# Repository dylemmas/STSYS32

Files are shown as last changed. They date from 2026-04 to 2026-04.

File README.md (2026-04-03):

# STASYS ESP32

Market-ready ESP32 firmware for shooter athlete muzzle trace and shot detection.

## Firmware Version
v1.0.0

## Hardware
- ESP32 DEVKIT V1
- MPU6050 (IMU: 6-axis accel+gyro, I2C)
- TP4056 (LiPo charge module)
- Piezoelectric vibration sensor
- LiPo 3.7V battery
- Picatinny rail mount

## Features
- Interrupt-driven MPU6050 sensor reading (1kHz)
- Dual-threshold shot detection (piezo + accelerometer)
- Configurable sample rate (50/100/200 Hz)
- Configurable shot detection thresholds
- Session management (start/stop, shot count, duration)
- Bluetooth Classic SPP binary protocol
- LED + haptic feedback on shot detection
- Battery monitoring with charging status
- NVS-based persistent configuration
- Watchdog timers for reliability
- I2C error recovery

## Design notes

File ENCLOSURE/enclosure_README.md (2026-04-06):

# STASYS Enclosure — 3D Printable Design

Parametric OpenSCAD models for the STASYS training device enclosure.

## Files

| File | Description |
|---|---|
| `STASYS_enclosure.scad` | Full parametric model (all-in-one, assembly view) |
| `enclosure_base.scad` | Base half only — export as STL for printing |
| `enclosure_lid.scad` | Lid half only — export as STL for printing |
| `enclosure_BOM.md` | Bill of materials + assembly guide |

## Quick Start

1. Install [OpenSCAD](https://openscad.org/) (free, Windows/Mac/Linux)
2. Open `enclosure_base.scad`
3. Press **F5** for preview or **F6** for full render
4. Press **F7** to export as STL
5. Repeat for `enclosure_lid.scad`
6. Slice in your slicer (PrusaSlicer, Cura, Lychee, etc.)
7. Print in PA12 SLS or high-strength SLA resin

## Design Overview

```
TOP VIEW (cross-section at Z=max)

        ┌─────────────────────────────────────┐
        │  ╔═══════════════════════════════╗  │
        │  ║                               ║  │
        │  ║     INTERNAL CAVITY           ║  │
        │  ║   ┌─────────────────────┐    ║  │
        │  ║   │   ESP32 DEVKIT V1   │    ║  │
        │  ║   │   + MPU6050 + wires │    ║  │
        │  ║   │   + LiPo battery   │    ║  │
        │  ║   └─────────────────────┘    ║  │
        │  ║                               ║  │
        │  ╚═══════════════════════════════╝  │
        └─────────────────────────────────────┘
              ↑↑       ↑↑  ← GASKET CHANNEL (perimeter)
             (slots straddle Picatinny rail slots)

FRONT VIEW

     ┌─────────────────────────┐
     │  LED PIPE  │  VENT PORT│
     ├─────────────────────────┤
     │                         │
     │    INTERNAL CAVITY      │
     │                         │
     ├─────────────────────────┤
     │         USB-C           │
     └─────────────────────────┘
              ↓
        PICATINNY RAIL
        (slots engage below)

BOTTOM VIEW

        ════════════════════     ← Picatinny rail slot
        │▓▓▓▓▓│     │▓▓▓▓▓│        ← Recoil lugs (2x)
        │     │     │     │
        │     └─────┘     │        ← Cross-bolt goes here
        │                 │
        └─────────────────┘
        ┌─────────────────┐
        │ ● ● ● ●        │        ← MPU6050 recess
        │    PIEZO ●     │        ← Piezo contact pad
        └─────────────────┘
```

## Key Dimensions

| Parameter | Value |
|---|---|
| Outer (W×D×H) | 65×50×34 mm |
| Internal cavity | 60×45×22 mm |
| Wall thickness | 2.5 mm |
| Base height | 8 mm |
| Lid height | 4 mm |
| Picatinny body | 24 mm (2 slots) |
| Recoil lug | 3 mm protrusion |
| Weight (printed PA12) | ~30g (base + lid) |
| Total with hardware | ~36g |
| Total on weapon | ~86g (with device) |

## Picatinny Rail Installation

1. Slide recoil lugs into Picatinny slot from the front
2. Slide device along rail until lugs sit in slot notch
3. Thread M3×16mm cross-bolt through base, into slot notch
4. Tighten to 0.5 N·m (hand tight + quarter turn)
5. Apply blue threadlocker to cross-bolt

## Parameter Customization

All key dimensions are defined at the top of each `.scad` file. Adjust these before rendering:

```scad
// Main dimensions
INNER_WIDTH = 60;      // Change if your PCB is wider
INNER_DEPTH = 45;      // Change if your PCB is deeper
WALL = 2.5;             // 2.0mm for SLA, 2.5mm for PA12

// Picatinny engagement
PICA_SLOTS = 2;         // 1 slot = less stable, 3 slots = more stable
RECOIL_LUG_H = 3.0;     // Increase if slot is deeper

// Component clearances
MPU6050_OFF_X = 6;      // Reposition MPU6050 pocket
PIEZO_PAD_D = 10;        // Larger/smaller piezo contact
```

## Recommended Print Settings

### PA12 SLS (recommended for base)
- Layer height: 60 µm
- Wall thickness: 2.5mm (3 perimeters)
- No supports needed (flat on build plate)
- Post-process: bead blast or tumble for surface smoothness

### High-Strength SLA
- Layer height: 50 µm
- Wall thickness: 2.0mm
- Material: Formlabs Durable, Siraya Tech Fast ABS, or equivalent
- Post-cure: 30 min at 60°C

## Post-Processing

1. **Heat-set inserts**: Soldering iron 250°C, press M3 brass inserts flush into base bosses
2. **Sand + prime**: 400-grit for support marks, filler primer for SLA
3. **Threadlocker**: Blue Loctite 243 on cross-bolt threads
4. **Silicone gasket**: Cut from 1mm sheet (see enclosure_BOM.md)

## Notes

- The base and lid are designed to be printed flat (no supports needed)
- PA12 SLS is recommended for the base due to fatigue resistance from recoil
- SLA resin is acceptable for the lid (non-structural)
- The Picatinny body extends 2.5mm beyond the main body on each side
- The recoil lugs are designed for MIL-STD-1913 Picatinny rails
- For Weaver rails (0.180" slots), file the lugs slightly narrower

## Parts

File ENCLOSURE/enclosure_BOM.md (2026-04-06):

# STASYS Enclosure — Bill of Materials

## 3D Printed Parts

| Qty | Part | File | Material | Print Orientation |
|-----|---|---|---|---|
| 1 | Base (bottom half + Picatinny rail) | `enclosure_base.scad` | PA12 SLS (recommended) | Flat on build plate |
| 1 | Lid (top half) | `enclosure_lid.scad` | PA12 SLS (recommended) | Flat on build plate |
| 1 | Silicone gasket (optional) | Cut from 1mm silicone sheet | Silicone rubber | N/A |

**Alternative materials**: High-strength SLA resin (Formlabs Durable, Siraya Tech Fast ABS-like). Avoid standard clear/white SLA — brittle under recoil.

## Hardware (Purchase)

### Fasteners

| Qty | Description | Spec | Notes |
|-----|---|---|---|
| 4 | M3×0.5×6mm countersunk head screw | ISO 7380 | Lid-to-base assembly |
| 1 | M3×0.5×16mm socket head cap screw | ISO 4762 | Picatinny cross-bolt |
| 4 | M3 brass heat-set threaded insert | OD 4.2mm, ID M3, length 5mm | Base screw bosses |
| 4 | M3 flat washer | OD 6mm, ID 3.2mm | Under cross-bolt / lid screws |
| 1 | Threadlocker (blue Loctite 243) | Medium strength | On cross-bolt threads |

### Threaded Insert Reference
Install heat-set inserts into base after printing:
- **Method**: Preheat soldering iron to 250°C, press insert flush
- **PA12**: Pre-heat insert area with hot air gun first
- **SLA resin**: Can insert directly, no pre-heat needed

### Vent Membrane (Optional — for IP54)

| Qty | Description | Spec | Source |
|-----|---|---|---|
| 1 | ePTFE breathable membrane | 6mm disc, 0.2mm thick | e.g., eWON Vent (Digikey: 1834-1015-ND) |
| 1 | Vent housing ring (3D printed) | Fits VENT_PORT_D recess | Print with lid |

### Gasket (Optional — for IP54)

Cut from 1mm silicone sheet (craft rubber or silicone gasket material):
- Trace the outer perimeter of the base top face
- Cut out the inner rectangle (gasket channel)
- Punch holes at 4 screw positions
- Punch hole at vent port center

## Assembly Guide

### Tools Required
- Phillips #0 screwdriver (for M3 countersunk screws)
- 2.5mm hex key / 2.5mm hex driver (for cross-bolt)
- Soldering iron with 4mm flat tip (for heat-set inserts)
- Calipers (to verify dimensions)
- Multimeter (for electrical testing)

### Assembly Steps

#### Step 1: Post-Processing (SLA parts)
1. Remove supports carefully
2. Wash in IPA (or water for water-washable resin)
3. Post-cure per resin manufacturer's instructions (30 min at 60°C for Formlabs)
4. Sand any support marks with 400-grit sandpaper
5. Fill and prime if desired for surface finish

#### Step 2: Install Heat-Set Inserts (Base)
1. Heat soldering iron to 250°C
2. Using tweezers, place insert into base screw boss hole
3. Press insert flush with flat face of iron
4. Insert should melt into plastic, sit 0.2mm below surface
5. Let cool 30 seconds before handling
6. Repeat for all 4 bosses

#### Step 3: Test Fit
1. Place ESP32 DEVKIT V1 into base cavity — verify clearances
2. Test lid fits on base — verify gasket channel alignment
3. Test M3 screws thread into inserts smoothly

#### Step 4: Wire Routing
1. Route USB-C cable from ESP32 to USB cutout on side
2. Route MPU6050 I2C wires to front area
3. Route piezo wire to piezo contact pad location
4. Use small zip ties or adhesive foam to secure wires

#### Step 5: Install Vent Membrane (Optional)
1. Apply thin layer of silicone adhesive around vent port recess
2. Press ePTFE membrane disc into recess
3. Let cure 24 hours before assembly

#### Step 6: Install Silicone Gasket (Optional)
1. Cut gasket from 1mm silicone sheet
2. Place gasket into base gasket channel
3. Verify gasket is seated fully in channel

#### Step 7: Final Assembly
1. Insert ESP32 DEVKIT V1 + wiring into base
2. Place lid on base — align carefully
3. Install 4× M3×6mm countersunk screws — snug, do not over-torque
4. Torque: 0.3–0.5 N·m (hand tight plus 1/4 turn with hex key)

#### Step 8: Picatinny Rail Installation
1. Slide recoil lug into Picatinny slot from the front
2. Slide device along rail until lug sits in slot notch
3. Thread M3×16mm cross-bolt through base, into slot notch
4. Tighten cross-bolt with hex key — 0.5 N·m (hand tight)
5. Apply blue threadlocker to bolt threads before final tightening

### Disassembly for Programming
1. Loosen cross-bolt, slide device off rail
2. Remove 4 lid screws
3. Lift lid off
4. Access USB-C port for programming
5. Reassemble in reverse order

## Dimension Summary

```
┌─────────────────────────────────────────────┐
│ ENCLOSURE OUTER (W×D×H): 65 × 50 × 34 mm   │
│ INTERNAL CAVITY (W×D×H): 60 × 45 × 22 mm   │
│ BASE HEIGHT: 8 mm                           │
│ LID HEIGHT: 4 mm                            │
│ WALL THICKNESS: 2.5 mm                      │
│ PICA BODY WIDTH: 24 mm (2-slot)            │
│ RECOIL LUG HEIGHT: 3 mm                     │
│ CROSS-BOLT: M3×16mm                        │
│ LID SCREWS: M3×6mm countersunk (4x)         │
│ BATTERY RECESS: 54×38×2 mm                 │
│ MPU6050 POCKET: 23×18×2 mm                 │
│ PIEZO PAD: Ø10mm × 2mm protrusion          │
│ LED PIPE: Ø2.5mm bore                      │
│ VENT PORT: Ø6mm recess                      │
│ USB CUTOUT: 10×8mm on side face             │
└─────────────────────────────────────────────┘
```

## Estimated Weight

| Component | Weight |
|---|---|
| Base (PA12 printed, ~25g) | ~20g |
| Lid (PA12 printed, ~12g) | ~10g |
| Gasket (silicone, 1mm) | ~2g |
| M3×6mm screws (4x) | ~2g |
| M3×16mm cross-bolt | ~1g |
| Heat-set inserts (4x) | ~1g |
| **Total** | **~36g** |
| + Device (ESP32 + components + battery) | ~50g |
| **Grand total on weapon** | **~86g** |

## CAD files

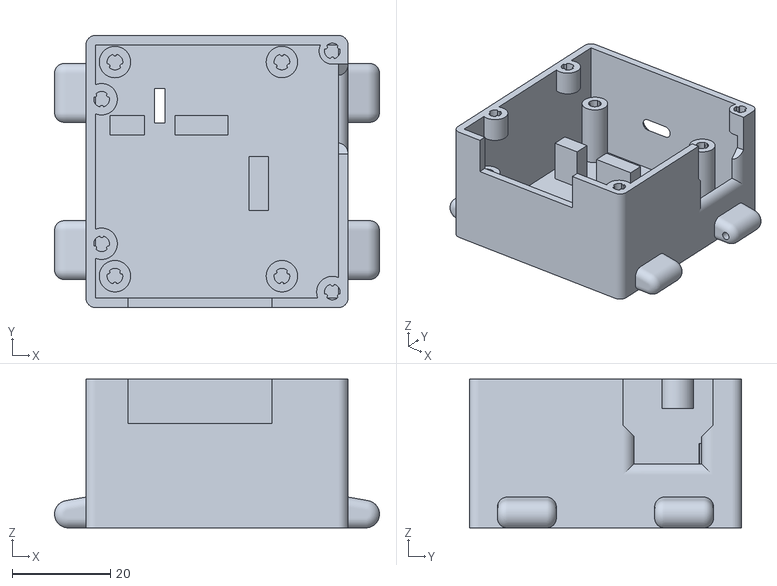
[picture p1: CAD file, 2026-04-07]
ENCLOSURE/MainCase watch esp 32.stl
66.2 x 55.5 x 30.3

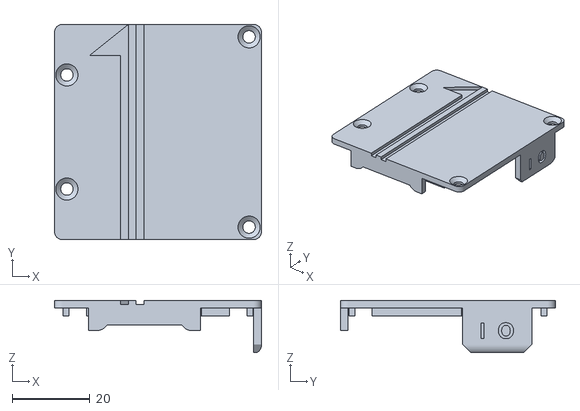
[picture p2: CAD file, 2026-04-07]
ENCLOSURE/Lid watch esp 32.stl
53.4 x 55.5 x 13.5

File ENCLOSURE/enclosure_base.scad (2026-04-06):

// STASYS Enclosure — BASE (Bottom Half)
// OpenSCAD model for SLA/SLS 3D printing
// Print: flat on build plate, no supports
//
// Hardware BOM: see enclosure_BOM.md
//
// Material: PA12 SLS recommended (tough, fatigue-resistant)
// SLA: use high-strength resin (Formlabs Durable, Siraya Tech Fast ABS)
//

// ===============================
// PARAMETERS
// ===============================
/* [Main Dimensions] */
INNER_WIDTH = 60;      // Internal X — must fit ESP32 DEVKIT V1 (~55mm)
INNER_DEPTH = 45;      // Internal Y — must fit DEVKIT V1 (~27mm) + wiring
INNER_HEIGHT = 22;     // Internal Z height — DEVKIT V1 (~20mm) + components
WALL = 2.5;           // Wall thickness: 2.0mm SLA, 2.5mm PA12/SLS
BASE_HEIGHT = 8;       // Height of Picatinny mount body (below cavity)
LID_HEIGHT = 4;        // Lid cap height

/* [Picatinny Rail Interface] */
PICA_SPACING = 10.01; // MIL-STD-1913 slot spacing
PICA_SLOTS = 2;        // Number of rail slots base straddles
CROSSBOLT_D = 3.0;     // Cross-bolt (M3) diameter
RECOIL_LUG_H = 3.0;    // Lug protrusion into Picatinny slot notch

/* [Components] */
MPU6050_OFFSET_X = 6;  // MPU6050 position from base inner corner
MPU6050_OFFSET_Y = 6;
MPU6050_W = 21;
MPU6050_D = 16;
BATTERY_L = 50;
BATTERY_W = 34;

/* [Hardware] */
SCREW_D = 3.0;         // M3 screw diameter
SCREW_HEAD_D = 6.0;    // M3 countersunk head diameter
SCREW_CSINK = 1.5;     // Countersink depth
INSERT_D = 4.4;         // M3 heat-set insert OD

/* [Gasket] */
GASKET_D = 1.0;        // Gasket channel depth (into base top face)
GASKET_W = 2.0;        // Gasket channel width

/* [Features] */
USB_W = 10;            // USB-C cutout width
LED_PIPE_D = 2.5;      // LED light pipe bore diameter
VENT_D = 6.0;          // Vent membrane port diameter
PIEZO_PAD_D = 10;      // Piezo contact pad diameter
PIEZO_PAD_H = 2;       // Piezo pad protrusion

$fn = 64;

// ===============================
// COMPUTED
// ===============================
OUTER_W = INNER_WIDTH + 2 * WALL;
OUTER_D = INNER_DEPTH + 2 * WALL;
OUTER_H = BASE_HEIGHT + INNER_HEIGHT + LID_HEIGHT;
PICA_BODY_W = PICA_SLOTS * PICA_SPACING + 4;

BOSS_INSET = 5;
boss_pos = [
    [BOSS_INSET, BOSS_INSET],
    [BOSS_INSET, OUTER_D - BOSS_INSET],
    [OUTER_W - BOSS_INSET, BOSS_INSET],
    [OUTER_W - BOSS_INSET, OUTER_D - BOSS_INSET]
];

// ===============================
// GASKET CHANNEL 2D — using offset for clean geometry
// ===============================
// Outer boundary minus inner boundary = channel ring
// offset(-GASKET_D) shrinks inner rect, creating channel
module gasket_channel_2d() {
    difference() {
        square([OUTER_W, OUTER_H]);
        offset(delta = -GASKET_D)
            square([OUTER_W, OUTER_H]);
    }
    // Also cut a ring around the inner island
    // (inner island: INNER_W × INNER_D, shrunk by GASKET_W)
    intersection() {
        difference() {
            offset(delta = -GASKET_D)
                square([OUTER_W, OUTER_H]);
            offset(delta = -(GASKET_D + GASKET_W))
                square([OUTER_W, OUTER_H]);
        }
        square([OUTER_W, OUTER_H]);
    }
}

// ===============================
// BASE — 2D profile then extrude
// ===============================
module base_profile_2d() {
    difference() {
        // Picatinny body extends beyond main body on X sides
        translate([(OUTER_W - PICA_BODY_W)/2, 0])
            square([PICA_BODY_W, OUTER_H]);

        // Main outer footprint (for union with Picatinny extension)
        union() {
            square([OUTER_W, OUTER_H]);
        }

        // Gasket channel on top face
        translate([0, BASE_HEIGHT + INNER_HEIGHT])
            gasket_channel_2d();

        // Screw counterbores (at top of base = lid mating face)
        translate([0, BASE_HEIGHT + INNER_HEIGHT])
            for (p = boss_pos)
                translate(p)
                    circle(d = SCREW_HEAD_D + 0.3);

        // Threaded insert holes (partially through top of base)
        translate([0, BASE_HEIGHT + INNER_HEIGHT - 2])
            for (p = boss_pos)
                translate(p)
                    circle(d = INSERT_D + 0.2);

        // LED pipe bore (through top)
        translate([OUTER_W - 10, OUTER_H + 1])
            circle(d = LED_PIPE_D + 0.5);

        // Vent port (center, for reference)
        translate([OUTER_W/2, OUTER_H/2])
            circle(d = VENT_D);
    }
}

// ===============================
// BASE 3D ASSEMBLY
// ===============================
// Outer shell
translate([0, 0, 0])
    linear_extrude(height = BASE_HEIGHT + INNER_HEIGHT)
        base_profile_2d();

// LED light pipe sleeve (protrudes above top face)
translate([OUTER_W - 10, OUTER_D/2, 0])
    cylinder(d = LED_PIPE_D - 0.5, h = BASE_HEIGHT + INNER_HEIGHT + 3);

// Cross-bolt channel (through Picatinny body, perpendicular to rail axis Y)
translate([(OUTER_W - PICA_BODY_W)/2 + 2, OUTER_D/2, 0])
    rotate([90, 0, 0])
        translate([0, 0, -PICA_BODY_W/2 - 2])
            cylinder(d = CROSSBOLT_D, h = PICA_BODY_W + 4);

// Screw through-holes (full depth)
for (p = boss_pos)
    translate([p[0], p[1], 0])
        cylinder(d = SCREW_D, h = BASE_HEIGHT + INNER_HEIGHT + LID_HEIGHT + 2);

// Counterbores
for (p = boss_pos)
    translate([p[0], p[1], BASE_HEIGHT + INNER_HEIGHT - SCREW_CSINK])
        cylinder(d = SCREW_HEAD_D + 0.3, h = SCREW_CSINK + 1);

// Threaded insert holes
for (p = boss_pos)
    translate([p[0], p[1], BASE_HEIGHT + INNER_HEIGHT])
        cylinder(d = INSERT_D, h = LID_HEIGHT + 2);

// USB cutout (Y=0 face)
translate([OUTER_W/2 - USB_W/2, -1, BASE_HEIGHT + INNER_HEIGHT/2 - 4])
    cube([USB_W, WALL + 2, 8]);

// LED bore (horizontal, through side)
translate([OUTER_W - 10, OUTER_D/2 + 2, BASE_HEIGHT + INNER_HEIGHT/2])
    rotate([0, 90, 0])
        cylinder(d = LED_PIPE_D + 0.5, h = WALL + 3);

// Recoil lugs (protrude from Picatinny body bottom)
translate([OUTER_W/2, 0, 0]) {
    half_span = (PICA_SLOTS * PICA_SPACING) / 2 - 1;
    for (x = [-half_span, half_span]) {
        translate([x, -0.1])
            hull() {
                circle(d = 6);
                translate([0, -RECOIL_LUG_H])
                    circle(d = 4);
            }
    }
}

// Interior cavity (hollow out)
translate([WALL, WALL, BASE_HEIGHT])
    cube([OUTER_W - 2*WALL, OUTER_D - 2*WALL, INNER_HEIGHT + 1]);

// PCB standoffs (inside base, on bottom)
translate([WALL, WALL, BASE_HEIGHT - 1]) {
    standoff_pos = [
        [BOSS_INSET + 2, BOSS_INSET + 2],
        [BOSS_INSET + 2, INNER_DEPTH - 2],
        [INNER_WIDTH - 2, BOSS_INSET + 2],
        [INNER_WIDTH - 2, INNER_DEPTH - 2]
    ];
    for (s = standoff_pos)
        translate([s[0], s[1], 0])
            cylinder(d = 4, h = 2);
}

// MPU6050 recess pocket (in base bottom)
translate([WALL + MPU6050_OFFSET_X, WALL + MPU6050_OFFSET_Y, 0])
    cube([MPU6050_W + 2, MPU6050_D + 2, 2]);

// Piezo contact pad (protrudes from base bottom for barrel contact)
translate([WALL + INNER_WIDTH - PIEZO_PAD_D - 4,
           WALL + INNER_DEPTH - PIEZO_PAD_D - 4,
           -PIEZO_PAD_H])
    cylinder(d = PIEZO_PAD_D, h = PIEZO_PAD_H);

// Battery recess in base (optional — battery can also sit in lid)
translate([WALL + 2, WALL + 2, BASE_HEIGHT + INNER_HEIGHT - BATTERY_L/2])
    rotate([90, 0, 0])
        cube([BATTERY_W + 2, 4, BATTERY_L + 2]);

// ===============================
// DIMENSIONS ECHO
// ===============================
echo("=== BASE DIMENSIONS ===");
echo(str("Outer (W×D×H): ", OUTER_W, "×", OUTER_D, "×", OUTER_H, " mm"));
echo(str("Internal cavity (W×D×H): ", INNER_WIDTH, "×", INNER_DEPTH, "×", INNER_HEIGHT, " mm"));
echo(str("Picatinny body: ", PICA_BODY_W, " mm wide (", PICA_SLOTS, " slots)"));
echo(str("Recoil lug height: ", RECOIL_LUG_H, " mm"));
echo(str("Cross-bolt: M3×", PICA_BODY_W + 4, " mm"));
echo(str("Lid screws: M3×6 mm CSK (4×)"));
echo(str("Wall thickness: ", WALL, " mm"));

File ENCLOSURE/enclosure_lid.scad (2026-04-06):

// STASYS Enclosure — LID (Top Half)
// OpenSCAD model for SLA/SLS 3D printing
// Print: flat on build plate (lid height), no supports
//
// Hardware BOM: see enclosure_BOM.md
//
// Material: PA12 SLS recommended
//

// ===============================
// PARAMETERS (must match base)
// ===============================
INNER_WIDTH = 60;
INNER_DEPTH = 45;
INNER_HEIGHT = 22;
WALL = 2.5;
BASE_HEIGHT = 8;
LID_HEIGHT = 4;

PICA_SPACING = 10.01;
PICA_SLOTS = 2;

SCREW_D = 3.0;
SCREW_HEAD_D = 6.0;
SCREW_CSINK = 1.5;
INSERT_D = 4.4;

GASKET_D = 1.0;
GASKET_W = 2.0;

BATTERY_L = 50;
BATTERY_W = 34;
VENT_D = 6.0;

$fn = 64;

// ===============================
// COMPUTED
// ===============================
OUTER_W = INNER_WIDTH + 2 * WALL;
OUTER_D = INNER_DEPTH + 2 * WALL;
PICA_BODY_W = PICA_SLOTS * PICA_SPACING + 4;

BOSS_INSET = 5;
boss_pos = [
    [BOSS_INSET, BOSS_INSET],
    [BOSS_INSET, OUTER_D - BOSS_INSET],
    [OUTER_W - BOSS_INSET, BOSS_INSET],
    [OUTER_W - BOSS_INSET, OUTER_D - BOSS_INSET]
];

// ===============================
// GASKET CHANNEL 2D (matches base)
// ===============================
module gasket_channel_2d() {
    difference() {
        square([OUTER_W, LID_HEIGHT]);
        offset(delta = -GASKET_D)
            square([OUTER_W, LID_HEIGHT]);
    }
    intersection() {
        difference() {
            offset(delta = -GASKET_D)
                square([OUTER_W, LID_HEIGHT]);
            offset(delta = -(GASKET_D + GASKET_W))
                square([OUTER_W, LID_HEIGHT]);
        }
        square([OUTER_W, LID_HEIGHT]);
    }
}

// ===============================
// LID PROFILE 2D
// ===============================
module lid_profile_2d() {
    difference() {
        // Picatinny body + main lid footprint
        translate([(OUTER_W - PICA_BODY_W)/2, 0])
            square([PICA_BODY_W, LID_HEIGHT]);
        square([OUTER_W, LID_HEIGHT]);

        // Screw counterbores (top surface)
        for (p = boss_pos)
            translate(p)
                circle(d = SCREW_HEAD_D + 0.3);

        // Vent port (center)
        translate([OUTER_W/2, OUTER_D/2])
            circle(d = VENT_D);
    }
}

// ===============================
// LID 3D
// ===============================
// Outer shell
linear_extrude(height = LID_HEIGHT)
    lid_profile_2d();

// Gasket channel on bottom face (complementary to base)
translate([0, 0, LID_HEIGHT - GASKET_D])
    linear_extrude(height = GASKET_D + 0.5)
        gasket_channel_2d();

// Screw through-holes
for (p = boss_pos)
    translate([p[0], p[1], 0])
        cylinder(d = SCREW_D, h = LID_HEIGHT + 1);

// Battery recess (bottom face — battery sits against PCB, lid clears it)
translate([WALL, WALL, -0.1])
    cube([BATTERY_L + 4, BATTERY_W + 4, LID_HEIGHT - GASKET_D + 0.1]);

// Vent membrane port (partial depth, to accept membrane disc)
translate([OUTER_W/2, OUTER_D/2, LID_HEIGHT - 2])
    cylinder(d = VENT_D - 1, h = 3);

echo("=== LID DIMENSIONS ===");
echo(str("Outer (W×D×H): ", OUTER_W, "×", OUTER_D, "×", LID_HEIGHT, " mm"));
echo(str("Battery recess: ", BATTERY_L+4, "×", BATTERY_W+4, "×", LID_HEIGHT - GASKET_D, " mm"));
echo(str("Vent port: Ø", VENT_D, " mm"));

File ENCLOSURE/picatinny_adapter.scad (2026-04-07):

// STASYS Picatinny Adapter Bracket
// Mounts the watch-style case to a Picatinny rail
// Measures from STL analysis of "MainCase watch esp 32.stl"
//
// Case: 66.2 x 55.5 x 30.3 mm overall
// Flat bottom: Z = 0 (reference)
// 4 bosses on bottom face: cylindrical features, dia ~3.8mm, rise ~2mm
//   BL: (-27.9, -18.9)  BR: (35.4, -18.9)
//   TL: (-27.4,  18.1)  TR: (34.3,  18.6)
//
// Print: PA12 SLS (recoil-safe), flat on build plate
// Assembly:
//   1. Drill 4x M3 clearance holes (3.2mm) through flat bottom at boss centers
//   2. Screw M3x0.5x12mm socket head caps through case bottom into adapter
//   3. Apply blue Loctite to M3x20mm cross-bolt
//   4. Slide adapter onto Picatinny rail
//   5. Tighten cross-bolt (hand tight + 1/4 turn, ~0.5 N·m)

// ===============================
// PARAMETERS
// ===============================

/* [Reference] */
// Case flat bottom face = Z = 0 (top of Picatinny body sits here)
// Bosses rise ~2mm above this plane
CASE_FLAT_Z = 0;

/* [4 Boss Positions — measured from STL] */
// Cylindrical bosses on case bottom face
// All 4 are used for maximum recoil resistance
BOSS_POSITIONS = [
    [-27.9, -18.9],  // bottom-left
     [35.4, -18.9],  // bottom-right
    [-27.4,  18.1],  // top-left
     [34.3,  18.6],  // top-right
];
BOSS_DIA = 3.8;    // boss outer diameter (mm) — M3 fits here
BOSS_RISE = 2.0;   // boss rise above flat bottom (mm)

/* [Adapter Body] */
// Full plate covers all 4 bosses
BODY_W = 70.0;      // adapter width (X)
BODY_D = 52.0;     // adapter depth (Y) — spans from Y~-24 to Y~+24
BODY_H = 6.0;       // body plate thickness — sits on flat bottom

/* [Picatinny Rail Interface] */
PICA_SLOTS = 2;         // slots to engage (2 = stable)
PICA_SLOT_W = 5.23;    // MIL-STD-1913 slot width
PICA_SPACING = 10.01;  // MIL-STD-1913 slot spacing
PICA_BODY_W = PICA_SLOTS * PICA_SPACING + 4.0;  // = 24mm
PICA_BODY_H = 10.0;    // height of Picatinny body below case

/* [Recoil Lugs] */
LUG_H = 3.0;    // protrusion into Picatinny slot
LUG_W = 4.5;    // lug width

/* [Cross-bolt] */
XBOLT_D = 3.0;          // M3 cross-bolt
XBOLT_HEAD_D = 5.5;     // M3 hex head
XBOLT_SOCKET = 2.5;     // M3 hex across-flats

/* [Mounting Screws] */
SCREW_D = 3.2;      // M3 clearance hole diameter
SCREW_CSK_D = 6.5; // M3 countersink diameter
SCREW_LEN = 14.0;  // M3x0.5x14mm — goes through flat bottom into boss

$fn = 64;

// ===============================
// COMPUTED
// ===============================
// Center of all 4 bosses
BOSS_CX = (BOSS_POSITIONS[0][0] + BOSS_POSITIONS[2][0] +
           BOSS_POSITIONS[1][0] + BOSS_POSITIONS[3][0]) / 4.0;
BOSS_CY = (BOSS_POSITIONS[0][1] + BOSS_POSITIONS[2][1] +
           BOSS_POSITIONS[1][1] + BOSS_POSITIONS[3][1]) / 4.0;

// Relative positions from boss cluster center
REL_BOSS = [
    [BOSS_POSITIONS[0][0] - BOSS_CX, BOSS_POSITIONS[0][1] - BOSS_CY],
    [BOSS_POSITIONS[1][0] - BOSS_CX, BOSS_POSITIONS[1][1] - BOSS_CY],
    [BOSS_POSITIONS[2][0] - BOSS_CX, BOSS_POSITIONS[2][1] - BOSS_CY],
    [BOSS_POSITIONS[3][0] - BOSS_CX, BOSS_POSITIONS[3][1] - BOSS_CY],
];

// Picatinny body centered on case
PICA_CX = BOSS_CX;   // center Picatinny body on boss cluster X
PICA_CY = BOSS_CY;   // center Picatinny body on boss cluster Y

// Recoil lug positions within Picatinny body
half_span = (PICA_SLOTS * PICA_SPACING) / 2.0 - LUG_W / 2.0;
LUG_X = [
    PICA_CX + half_span,
    PICA_CX - half_span
];

// Total adapter height
TOTAL_H = BODY_H + PICA_BODY_H;

// ===============================
// MODULES
// ===============================

// Recoil lug 2D (cross-section)
module lug_2d() {
    hull() {
        circle(d = LUG_W + 1.5);
        translate([0, -LUG_H])
            circle(d = LUG_W - 0.5);
    }
}

// Full adapter
module stasys_picatinny_adapter() {
    difference() {
        union() {
            // --- Main plate (sits on flat bottom) ---
            translate([-BODY_W/2, -BODY_D/2, CASE_FLAT_Z])
                cube([BODY_W, BODY_D, BODY_H]);

            // --- Picatinny body (extends below case) ---
            translate([PICA_CX - PICA_BODY_W/2, -BODY_D/2, CASE_FLAT_Z - PICA_BODY_H])
                cube([PICA_BODY_W, BODY_D, PICA_BODY_H]);

            // --- Recoil lugs (protrude below Picatinny body) ---
            for (lx in LUG_X) {
                translate([lx, -BODY_D/2 - 1, CASE_FLAT_Z - PICA_BODY_H - LUG_H])
                    rotate([-90, 0, 0])
                        linear_extrude(height: BODY_D + 2)
                            lug_2d();
            }
        }

        // --- M3 clearance holes (through entire adapter) ---
        for (b in REL_BOSS) {
            translate([BOSS_CX + b[0], BOSS_CY + b[1], CASE_FLAT_Z - PICA_BODY_H - 2])
                cylinder(d = SCREW_D, h = TOTAL_H + 4);
        }

        // --- M3 countersinks (top face) ---
        for (b in REL_BOSS) {
            translate([BOSS_CX + b[0], BOSS_CY + b[1], CASE_FLAT_Z + TOTAL_H - 2.0])
                cylinder(d = SCREW_CSK_D, h = 2.5);
        }

        // --- Cross-bolt channel (horizontal, along Y axis) ---
        // Goes through Picatinny body, threads into rail slot walls
        translate([PICA_CX, 0, CASE_FLAT_Z - PICA_BODY_H/2])
            rotate([90, 0, 0])
                translate([0, 0, -BODY_D/2 - 2])
                    cylinder(d = XBOLT_D + 0.4, h = BODY_D + 4);

        // --- Cross-bolt hex socket (top face, centered on Picatinny body) ---
        // Counterbore for hex head
        translate([PICA_CX, PICA_CY, CASE_FLAT_Z + TOTAL_H - 1.5])
            cylinder(d = XBOLT_HEAD_D + 1.0, h = 2.5);
        // Hex socket
        translate([PICA_CX, PICA_CY, CASE_FLAT_Z + TOTAL_H - 1.0])
            cylinder(d = XBOLT_SOCKET, h = BODY_H + PICA_BODY_H + 2, $fn = 6);
    }
}

// Ghost: case bottom outline + boss indicators
module case_ghost() {
    // Flat bottom face outline
    translate([-33, -25.5, CASE_FLAT_Z + 0.3])
        cube([66, 55, 0.3]);

    // Boss indicators
    for (b in REL_BOSS) {
        color([0.8, 0.2, 0.2, 0.5])
        translate([BOSS_CX + b[0], BOSS_CY + b[1], CASE_FLAT_Z + BOSS_RISE])
            cylinder(d = BOSS_DIA + 0.2, h = 0.3);
    }
}

// ===============================
// RENDER
// ===============================
stasys_picatinny_adapter();
case_ghost();

// ===============================
// INFO
// ===============================
echo("=== PICATINNY ADAPTER (MEASURED) ===");
echo("Case boss positions (from STL):");
for (i = [0:3]) {
    echo(str("  ", i+1, ": (", BOSS_POSITIONS[i][0]:5.1f, ", ", BOSS_POSITIONS[i][1]:5.1f, ")"));
}
echo(str("Boss cluster center: (", BOSS_CX:5.1f, ", ", BOSS_CY:5.1f, ")"));
echo(str("Boss diameter: ", BOSS_DIA, "mm"));
echo(str("Boss rise: ", BOSS_RISE, "mm above flat bottom"));
echo("");
echo(str("Adapter body: ", BODY_W, "x", BODY_D, "x", BODY_H, " mm"));
echo(str("Picatinny body: ", PICA_BODY_W, "x", BODY_D, "x", PICA_BODY_H, " mm (", PICA_SLOTS, " slots)"));
echo(str("Picatinny center: (", PICA_CX:5.1f, ", ", PICA_CY:5.1f, ")"));
echo(str("Recoil lug positions: X=", LUG_X[0]:5.1f, " and X=", LUG_X[1]:5.1f));
echo(str("Recoil lug: ", LUG_W, "x", LUG_H, " mm"));
echo(str("Cross-bolt: M3x", PICA_BODY_H + 10, "mm (hex socket from top)"));
echo(str("Mounting screws: M3x", SCREW_LEN, "mm (4x, through flat bottom)"));
echo(str("Total adapter height: ", TOTAL_H, "mm (", BODY_H, " plate + ", PICA_BODY_H, "mm Pica body)"));
echo(str("Protrudes below case: ", PICA_BODY_H + LUG_H, "mm total"));
echo("");
echo("=== HARDWARE LIST ===");
echo("  4x M3x0.5x14mm socket head cap screw (case -> adapter)");
echo("  4x M3 flat washer");
echo("  1x M3x0.5x20mm socket head cap screw (cross-bolt)");
echo("  Blue Loctite 243 on cross-bolt");

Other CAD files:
ENCLOSURE/STASYS_enclosure.scad

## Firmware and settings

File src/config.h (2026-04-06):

#ifndef CONFIG_H
#define CONFIG_H

#include <stdint.h>
#include <stdbool.h>
#include <freertos/FreeRTOS.h>
#include <freertos/semphr.h>

// ================= CONFIG STRUCT =================
struct FirmwareConfig {
    uint8_t  sample_rate_hz;     // 50, 100, 200
    uint16_t piezo_threshold;    // ADC threshold (default 800)
    uint16_t accel_threshold;    // Jerk threshold raw LSB (default 300)
    uint16_t debounce_ms;        // Min ms between shots (default 200)
    bool     led_enabled;        // LED feedback
    uint8_t  data_mode;         // 0=both, 1=raw-only, 2=events-only
    uint16_t streaming_rate_hz;  // Raw stream rate
    char     device_name[20];   // BT device name (matches PktConfig protocol)
    bool     adaptive_threshold_enabled;  // Enable adaptive threshold (Phase 1.3)
};

// ================= CALIBRATION DATA =================
struct CalibrationData {
    int16_t  accel_bias_x;
    int16_t  accel_bias_y;
    int16_t  accel_bias_z;
    int16_t  gyro_bias_x;
    int16_t  gyro_bias_y;
    int16_t  gyro_bias_z;
    int16_t  temp_coeff;        // degC offset per degC from 25C reference
    uint8_t  mount_mode;        // 0=standard, 1=rotated_90, 2=inverted, 3=rotated_270
                                 // 4=barrel_under (90° pitch, Z along barrel)
                                 // 5=barrel_under_inv (270° pitch)
                                 // 6=side_mount (90° roll)
    bool     is_calibrated;
    bool     factory_calibrated;
};

// ================= ADAPTIVE THRESHOLD STATE =================
// Persisted to NVS "calib" namespace on session stop, restored on boot.
struct AdaptiveThresholdState {
    uint16_t shot_peaks[10];         // Ring buffer of last 10 piezo peaks
    uint8_t  shot_peak_count;        // Number of shots in ring buffer (0-10)
    uint32_t adaptive_threshold;     // Current adaptive threshold (mean + 2*stddev)
    uint8_t  adaptive_enabled;        // Whether adaptive threshold is enabled
};

// ================= EXTERNALS =================
extern SemaphoreHandle_t configMutex;
extern FirmwareConfig g_config;

// ================= DEFAULTS =================
#define DEFAULT_SAMPLE_RATE       100
#define DEFAULT_PIEZO_THRESHOLD   800
#define DEFAULT_ACCEL_THRESHOLD   300
#define DEFAULT_DEBOUNCE_MS       200
#define DEFAULT_LED_ENABLED       true
#define DEFAULT_DATA_MODE         0    // both
#define DEFAULT_STREAMING_RATE    100
#define DEFAULT_DEVICE_NAME       "STASYS"

// ================= FUNCTIONS =================
void  initConfig();
void  loadConfig(FirmwareConfig* cfg);
bool  saveConfig(const FirmwareConfig* cfg);
void  updateConfig(const FirmwareConfig* newCfg);
void  getConfigCopy(FirmwareConfig* outCfg);  // Thread-safe copy

// Adaptive threshold persistence (NVS "calib" namespace)
bool  saveAdaptiveThreshold(const struct AdaptiveThresholdState* state);
bool  loadAdaptiveThreshold(struct AdaptiveThresholdState* out);

#endif // CONFIG_H

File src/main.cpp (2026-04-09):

#include <Arduino.h>
#include <freertos/FreeRTOS.h>
#include <freertos/task.h>
#include <esp_task_wdt.h>
#include <esp_timer.h>
#include <nvs_flash.h>
#include <esp_system.h>
#include <esp_efuse.h>
#include <esp_flash_encrypt.h>
#include <esp_efuse_table.h>

// Core headers
#include "protocol.h"
#include "sensor.h"
#include "config.h"
#include "session.h"
#include "shot_detector.h"
#include "security.h"
#include "bluetooth.h"
#include "battery.h"
#include "led.h"
#include "storage.h"
#include "ota.h"

// ================= CONFIGURATION =================
#define SENSOR_TASK_STACK   4096
#define DETECTOR_TASK_STACK  4096
#define STREAM_TASK_STACK    2048
#define BATTERY_TASK_STACK   1024
#define RECOVERY_TASK_STACK 2048

#define BATTERY_INTERVAL_MS  30000UL  // 30s between battery reads

// ================= QUEUES =================
QueueHandle_t sampleQueue    = NULL;
QueueHandle_t shotEventQueue = NULL;
QueueHandle_t streamQueue    = NULL;  // Separate queue for streaming (Fix: stream task)

// ================= STATS =================
static uint32_t s_sampleCounter = 0;
static uint32_t s_droppedSamples = 0;
static uint32_t s_shotsDetected = 0;
static uint32_t s_lastBatteryUpdate = 0;
static uint32_t s_lastActivityTime = 0;
static bool s_sleepScheduled = false;

#define IDLE_TIMEOUT_MS (5UL * 60 * 1000)  // 5 minutes idle → sleep

// ================= POWER MANAGEMENT =================
static void recordActivity() {
    s_lastActivityTime = millis();
    s_sleepScheduled = false;
}

static void checkIdleSleep() {
    uint32_t now = millis();

    // NEVER sleep on battery power — keep BT discoverable at all times.
    // Only allow light sleep when externally powered (charging via USB/TP4056).
    if (isBatteryCharging()) {
        if (!s_sleepScheduled) {
            if (now - s_lastActivityTime > IDLE_TIMEOUT_MS) {
                Serial.println("[PWR] Idle timeout reached (charging), entering light sleep...");
                s_sleepScheduled = true;
                esp_sleep_enable_timer_wakeup(10 * 1000000ULL);
                esp_light_sleep_start();
                s_sleepScheduled = false;
                recordActivity();
                Serial.println("[PWR] Woke from light sleep");
            }
        }
    } else {
        // On battery: keep BT radio always active, no sleep allowed.
        s_sleepScheduled = false;
        recordActivity();  // Keep activity timer fresh so sleep is never re-scheduled
    }
}

// ================= FIRMWARE VERSION =================
#define FIRMWARE_VERSION_MAJOR 1
#define FIRMWARE_VERSION_MINOR 0
#define FIRMWARE_VERSION_PATCH 0
#define FIRMWARE_VERSION ((FIRMWARE_VERSION_MAJOR << 16) | (FIRMWARE_VERSION_MINOR << 8) | FIRMWARE_VERSION_PATCH)

// ================= TASK FUNCTIONS =================

// --- Recovery Task (Core 1, Medium Priority) ---
// Runs I2C bus recovery asynchronously so sensor task isn't blocked
void recoveryTask(void* param) {
    (void)param;
    Serial.println("[RECOVERY] Task started");
    esp_task_wdt_add(NULL);

    for (;;) {
        // Guard against recoveryQueue not being created (MPU6050 may not be detected)
        if (recoveryQueue != NULL) {
            bool signal;
            if (xQueueReceive(recoveryQueue, &signal, pdMS_TO_TICKS(1000)) == pdTRUE) {
                Serial.println("[RECOVERY] I2C error detected, attempting recovery...");
                // Run synchronous recovery (this blocks the recovery task, not sensor task)
                recoverI2CBus();
                Serial.printf("[RECOVERY] Done. success=%d, fail_count=%d\n", g_recoverySuccess, s_recoveryFailCount);
                s_consecutiveErrors = 0;  // Reset from sensor.cpp's view
            }
        } else {
            vTaskDelay(pdMS_TO_TICKS(1000));  // Wait without busy-waiting
        }
    }
}

// --- Sensor Task (Core 1, High Priority) ---
void sensorTask(void* param) {
    (void)param;

    Serial.println("[SENSOR] Task started");
    esp_task_wdt_add(NULL);

    SensorSample sample;

    for (;;) {
        // Block on data-ready semaphore (set by ISR)
        // Guard against NULL semaphore when MPU6050 is not detected
        if (dataReadySem != NULL && xSemaphoreTake(dataReadySem, pdMS_TO_TICKS(5)) == pdTRUE) {
            // Read sensor immediately
            if (readSensorBurst(&sample)) {
                // Push to both queues (non-blocking). Each consumer drains its own queue.
                if (sampleQueue != NULL) {
                    if (xQueueSendToBack(sampleQueue, &sample, 0) != pdTRUE) {
                        s_droppedSamples++;
                    }
                }
                if (streamQueue != NULL) {
                    xQueueSendToBack(streamQueue, &sample, 0);
                }
                s_sampleCounter++;
            }
        } else {
            // Timeout or no semaphore: sensor stalled. Do a polling fallback read.
            if (readSensorBurst(&sample)) {
                if (sampleQueue != NULL) {
                    xQueueSendToBack(sampleQueue, &sample, 0);
                }
                if (streamQueue != NULL) {
                    xQueueSendToBack(streamQueue, &sample, 0);
                }
                s_sampleCounter++;
            }
        }
        // Always reset WDT to prevent timeout even when sensor is absent
        esp_task_wdt_reset();
    }
}

// --- Shot Detector Task (Core 1, Medium Priority) ---
void shotDetectorTask(void* param) {
    (void)param;

    Serial.println("[DETECTOR] Task started");
    esp_task_wdt_add(NULL);

    SensorSample sample;
    ShotEvent event;
    FirmwareConfig cfg;
    uint32_t configRefreshCounter = 0;

    // Initial config load
    getConfigCopy(&cfg);
    updateShotDetectorConfig(&cfg);

    for (;;) {
        if (sampleQueue != NULL && xQueueReceive(sampleQueue, &sample, pdMS_TO_TICKS(10)) == pdTRUE) {
            // Periodically refresh config (every 100 samples)
            if (++configRefreshCounter >= 100) {
                getConfigCopy(&cfg);
                updateShotDetectorConfig(&cfg);
                configRefreshCounter = 0;
            }

            // Only process if session is active
            if (getSessionState() == SessionState::STREAMING) {
                bool shotDetected = processSample(&sample, &event,
                                                  g_lastSession.session_id);
                if (shotDetected) {
                    s_shotsDetected++;
                    addShotToSession(&event);

                    // Send shot event immediately — must not be queued behind samples
                    sendPacketImmediate(PKT_TYPE_EVT_SHOT_DETECTED, &event, sizeof(event));

                    // LED + haptic feedback
                    triggerShotFeedback();

                    // Also send shot via event queue for any other consumers
                    if (shotEventQueue != NULL) {
                        xQueueSendToBack(shotEventQueue, &event, 0);
                    }
                }
            }
        }
        vTaskDelay(pdMS_TO_TICKS(1));
        esp_task_wdt_reset();  // Prevent WDT timeout during idle polling
    }
}

// --- Stream Task (Core 0, Low Priority) ---
void streamTask(void* param) {
    (void)param;

    Serial.println("[STREAM] Task started");
    esp_task_wdt_add(NULL);

    SensorSample sample;
    FirmwareConfig cfg;
    uint32_t lastStreamTime_us = 0;
    uint32_t streamInterval_us = 10000; // default 100Hz
    uint32_t configRefreshCounter = 0;

    getConfigCopy(&cfg);

    for (;;) {
        uint32_t now = esp_timer_get_time();

        // Refresh config periodically
        if (++configRefreshCounter >= 500) {
            getConfigCopy(&cfg);
            streamInterval_us = 1000000 / cfg.streaming_rate_hz;
            configRefreshCounter = 0;
        }

        // Check data mode: 0=both, 1=raw-only, 2=events-only
        if (cfg.data_mode == 2) {
            // Events only — drain the stream queue to avoid buildup
            if (streamQueue != NULL) {
                while (xQueueReceive(streamQueue, &sample, 0) == pdTRUE) {}
            }
            vTaskDelay(pdMS_TO_TICKS(10));
            continue;
        }

        if (getSessionState() == SessionState::STREAMING) {
            if (now - lastStreamTime_us >= streamInterval_us) {
                lastStreamTime_us = now;

                // Drain all queued samples except the last one (latest)
                SensorSample lastSample;
                bool gotSample = false;
                if (streamQueue != NULL) {
                    while (xQueueReceive(streamQueue, &sample, 0) == pdTRUE) {
                        lastSample = sample;
                        gotSample = true;
                    }
                }

                // Send the latest sample (non-blocking via TX queue)
                if (gotSample) {
                    PktRawSample pkt;
                    pkt.sample_counter = s_sampleCounter;
                    pkt.timestamp_us = lastSample.timestamp_us;
                    pkt.accel_x = lastSample.accel_x;
                    pkt.accel_y = lastSample.accel_y;
                    pkt.accel_z = lastSample.accel_z;
                    pkt.gyro_x = lastSample.gyro_x;
                    pkt.gyro_y = lastSample.gyro_y;
                    pkt.gyro_z = lastSample.gyro_z;
                    pkt.piezo = lastSample.piezo;
                    pkt.temperature = lastSample.temperature;

                    sendPacket(PKT_TYPE_DATA_RAW_SAMPLE, &pkt, sizeof(pkt));
                }
            }
        } else {
            // Not streaming — drain stream queue to prevent buildup
            if (streamQueue != NULL) {
                while (xQueueReceive(streamQueue, &sample, 0) == pdTRUE) {}
            }
        }

        vTaskDelay(pdMS_TO_TICKS(1));
        esp_task_wdt_reset();
    }
}

// --- Battery Monitor Task (Core 0, Low Priority) ---
void batteryMonitorTask(void* param) {
    (void)param;

    Serial.println("[BATTERY] Task started");
    esp_task_wdt_add(NULL);

    int lastReportedVal = -1;

    for (;;) {
        updateBattery();
        uint8_t currentVal = getBatteryPercent();

        // Reset idle timer (periodic activity)
        recordActivity();

        if (lastReportedVal < 0 || abs((int)currentVal - (int)lastReportedVal) >= 2) {
            lastReportedVal = currentVal;
        }

        // Low battery warning via LED
        BatteryStatus st = readBattery();
        if (st.isLow && !st.isCharging) {
            setLEDMode(LEDMode::LOW_BATTERY);
        }

        // Periodic health report
        if (s_sampleCounter > 0 && (s_sampleCounter % 10000 == 0)) {
            Serial.printf("[STATS] samples=%lu dropped=%lu shots=%lu batt=%d%%\n",
                         s_sampleCounter, s_droppedSamples, s_shotsDetected, currentVal);
        }

        vTaskDelay(pdMS_TO_TICKS(BATTERY_INTERVAL_MS / portTICK_PERIOD_MS));
        esp_task_wdt_reset();
    }
}

// --- Bluetooth Task (Core 0, High Priority) ---
void bluetoothTask(void* param) {
    (void)param;

    Serial.println("[BT] Task started");
    esp_task_wdt_add(NULL);

    DecodedPacket cmd;
    uint32_t lastHeartbeat_ms = 0;
    const uint32_t HEARTBEAT_INTERVAL_MS = 5000;  // Send health every 5s during session
    bool wasConnected = false;

    for (;;) {
        // Check connection state
        bool connected = SerialBT.connected();
        if (connected != g_btConnected) {
            g_btConnected = connected;
            if (connected) {
                Serial.println("[BT] Connected");
                setLEDMode(LEDMode::CONNECTED);
                // Clear stale RX data from previous connection
                s_rxLen = 0;

                // Auto-stop any active session on disconnect
                if (getSessionState() == SessionState::STREAMING) {
                    stopSession();
                    PktSessionStopped pkt;
                    pkt.session_id = g_lastSession.session_id;
                    pkt.duration_ms = g_lastSession.duration_ms;
                    pkt.shot_count = g_lastSession.shot_count;
                    pkt.battery_end = getBatteryPercent();
                    pkt.sensor_health = getSensorHealthFlags();
                    sendPacketImmediate(PKT_TYPE_EVT_SESSION_STOPPED, &pkt, sizeof(pkt));
                }
                wasConnected = true;
            } else {
                Serial.println("[BT] Disconnected");
                // Fix: Immediately restart advertising for automatic reconnection.
                // ESP32 continues to advertise as "STASYS" so Android can reconnect
                // without power cycling the device.
                esp_err_t err = esp_bt_gap_set_scan_mode(
                    ESP_BT_CONNECTABLE, ESP_BT_GENERAL_DISCOVERABLE);
                if (err != ESP_OK) {
                    Serial.printf("[BT] Re-advertise failed: %d, restarting SPP...\n", err);
                    // If advertising can't be restored, restart the BT serial service
                    FirmwareConfig cfg;
                    getConfigCopy(&cfg);
                    SerialBT.begin(cfg.device_name);
                    esp_bt_gap_set_scan_mode(ESP_BT_CONNECTABLE, ESP_BT_GENERAL_DISCOVERABLE);
                } else {
                    Serial.println("[BT] Re-advertising for reconnect...");
                }
                setLEDMode(LEDMode::IDLE);
                // Clear RX buffer on disconnect
                s_rxLen = 0;
                lastHeartbeat_ms = 0;  // Reset heartbeat on disconnect
            }
        }

        // Heartbeat: send sensor health every 5s during active sessions.
        // This lets the Android app detect dead connections and serves as keepalive.
        if (g_btConnected && getSessionState() == SessionState::STREAMING) {
            uint32_t now = millis();
            if (now - lastHeartbeat_ms >= HEARTBEAT_INTERVAL_MS) {
                lastHeartbeat_ms = now;
                sendSensorHealthPacket();
                Serial.println("[BT] Heartbeat sent");
            }
        }

        // Read incoming BT data
        int available = SerialBT.available();
        if (available > 0) {
            // Debug: log incoming data periodically
            static uint32_t s_debugRxCount = 0;
            if (s_debugRxCount < 5 || available > 0) {
                s_debugRxCount += available;
                Serial.printf("[BT] RX: %d bytes avail (total seen=%lu)\n",
                             available, s_debugRxCount);
            }

            int toRead = min(available, (int)(sizeof(s_rxBuffer) - s_rxLen));
            if (toRead == 0) {
                // Buffer full — don't discard everything, just wait for drain
                s_rxOverflowCount++;
                Serial.printf("[BT] RX overflow #%lu (buffer full)\n", s_rxOverflowCount);
                vTaskDelay(pdMS_TO_TICKS(5));  // Let buffer drain
                continue;
            }
            int bytesRead = SerialBT.readBytes(s_rxBuffer + s_rxLen, toRead);
            if (bytesRead > 0) {
                s_rxLen += bytesRead;

                // Parse through buffer
                uint16_t consumed = 0;
                for (uint16_t i = 0; i < s_rxLen; ) {
                    bool found = false;
                    uint16_t best = 0;

                    // Try to find complete packet
                    for (uint16_t j = 0; j < s_rxLen - i; j++) {
                        if (decodeByte(s_rxBuffer[i + j], &cmd)) {
                            found = true;
                            best = i + j + 1;
                            dispatchCommand(&cmd);
                            break;
                        }
                    }

                    if (found) {
                        consumed = best;
                        // Shift remaining data
                        memmove(s_rxBuffer, s_rxBuffer + consumed, s_rxLen - consumed);
                        s_rxLen -= consumed;
                        consumed = 0;
                        break;
                    } else {
                        // Check if sync byte 0xAA is in buffer, shift to it
                        bool foundSync = false;
                        for (uint16_t j = 1; j < s_rxLen - i; j++) {
                            if (s_rxBuffer[i + j] == SYNC_BYTE_0) {
                                memmove(s_rxBuffer, s_rxBuffer + i + j,
                                        s_rxLen - i - j);
                                s_rxLen -= (i + j);
                                foundSync = true;
                                break;
                            }
                        }
                        if (!foundSync) {
                            s_rxLen = 0; // No sync found, discard
                        }
                        break;
                    }
                }
            }
        }

        // Send outgoing TX queue packets + flow control
        TXItem txItem;
        UBaseType_t qlen = uxQueueMessagesWaiting(txQueue);

        // Flow control: send raw XON/XOFF bytes outside packet framing.
        // Fix: was using type 0x14 (EVT_AUTH_CHALLENGE) as a packet type,
        // which conflicted with the protocol. Now sending as raw RFCOMM bytes.
        static bool s_flowPaused = false;
        if (s_flowPaused && qlen < 16) {
            SerialBT.write(0x11);  // XON (ASCII DC1)
            s_flowPaused = false;
            Serial.println("[BT] XON sent (raw)");
        }

        while (xQueueReceive(txQueue, &txItem, 0) == pdTRUE) {
            SerialBT.write(txItem.data, txItem.length);
            // XOFF when queue exceeds 48
            if (!s_flowPaused && uxQueueMessagesWaiting(txQueue) > 48) {
                SerialBT.write(0x13);  // XOFF (ASCII DC3) — sent as raw byte
                s_flowPaused = true;
                Serial.println("[BT] XOFF sent (raw)");
            }
        }

        vTaskDelay(pdMS_TO_TICKS(1));
        esp_task_wdt_reset();
    }
}

// ================= JTAG DISABLE =================
// Permanently disables JTAG interface via efuses.
// Call AFTER security init, before any task starts (in case JTAG was used
// to flash the chip). Burns DIS_JTAG efuse bit — this is IRREVERSIBLE.
// If JTAG is already disabled, this is a no-op (safe to call every boot).
// NOTE: JTAG can only be disabled via efuse burn, not software reset.
//       This function is safe because burning an already-set efuse bit is a no-op.
static void disableJTAG() {
    esp_err_t err = esp_efuse_write_field_bit(ESP_EFUSE_DISABLE_JTAG);
    if (err == ESP_OK) {
        Serial.println("[MAIN] JTAG disabled via efuse");
    } else if (err == ESP_ERR_EFUSE_REPEATED_PROG) {
        // Already disabled — this is the expected case on subsequent boots
        Serial.println("[MAIN] JTAG already disabled (efuse burned)");
    } else {
        Serial.printf("[MAIN] JTAG disable warning: %d\n", err);
    }
}
// ESP32 flash encryption uses transparent XTS-128 — the CPU always sees
// plaintext. Raw flash dumps are unreadable when flash encryption is
// enabled via efuse. All NVS namespaces (config, battery, sensor, calib)
// are automatically encrypted at rest without additional key management.
// This function checks the flash encryption status and initializes NVS.
static void initNVS() {
    if (esp_flash_encryption_enabled()) {
        Serial.println("[MAIN] NVS: transparent flash encryption active (XTS-128)");
    }

    esp_err_t nvs_err = nvs_flash_init();
    if (nvs_err == ESP_ERR_NVS_NO_FREE_PAGES ||
        nvs_err == ESP_ERR_INVALID_STATE) {
        nvs_flash_erase();
        nvs_err = nvs_flash_init();
    }
    if (nvs_err == ESP_OK) {
        Serial.println("[MAIN] NVS: initialized");
    } else {
        Serial.printf("[MAIN] NVS: init failed (%d)\n", nvs_err);
    }
}

static void checkSecurityStatus() {
    bool efuse_provisioned = isDeviceSecretProvisioned();
    if (!efuse_provisioned) {
        Serial.println("[MAIN] SECURITY: WARNING — no efuse device secret provisioned");
        Serial.println("[MAIN] SECURITY: WARNING — using MAC-based secret (dev mode only)");
    } else {
        Serial.println("[MAIN] SECURITY: efuse device secret detected (production mode)");
    }

    if (esp_flash_encryption_enabled()) {
        Serial.println("[MAIN] SECURITY: flash encryption ENABLED");
    } else {
        Serial.println("[MAIN] SECURITY: flash encryption NOT enabled (run secure boot script)");
    }
}
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
void loop() {
    // All work is done in FreeRTOS tasks
    // Power management: check idle sleep periodically
    checkIdleSleep();
    vTaskDelay(pdMS_TO_TICKS(1000));
}

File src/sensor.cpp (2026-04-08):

#include "sensor.h"
#include <Arduino.h>
#include <Wire.h>
#include <esp_timer.h>
#include "config.h"
#include <Preferences.h>

// ================= I2C BUS SCAN =================
void scanI2CBus() {
    Serial.println("[SENSOR] Scanning I2C bus...");
    Wire.begin(I2C_SDA, I2C_SCL);
    Wire.setClock(400000);
    delay(50);
    uint8_t found = 0;
    for (uint8_t addr = 1; addr < 127; addr++) {
        Wire.beginTransmission(addr);
        uint8_t err = Wire.endTransmission();
        if (err == 0) {
            // Read WHO_AM_I if it's a known sensor
            uint8_t whoami = 0xFF;
            if (addr == 0x68 || addr == 0x69) {
                Wire.beginTransmission(addr);
                Wire.write(0x75); // WHO_AM_I
                Wire.endTransmission(false);
                Wire.requestFrom(addr, (uint8_t)1);
                if (Wire.available()) whoami = Wire.read();
            }
            Serial.printf("  [SENSOR] I2C addr=0x%02X (%s) WHOAMI=0x%02X\n",
                          addr, (addr == 0x68 ? "MPU default" : addr == 0x69 ? "MPU alt" : "other"), whoami);
            found++;
        } else if (err == 4) {
            Serial.printf("  [SENSOR] I2C addr=0x%02X: unknown error\n", addr);
        }
    }
    Serial.printf("[SENSOR] Scan complete: %d device(s) found\n", found);
}

// ================= GLOBALS =================
SemaphoreHandle_t dataReadySem = NULL;
QueueHandle_t recoveryQueue = NULL;
volatile bool g_sensorDegraded = false;

// Recovery completion notification — RecoveryTask signals this after a
// successful reinit so sensorTask can update g_sensorDegraded.
SemaphoreHandle_t recoveryDoneSem = NULL;
bool g_recoverySuccess = false;

// Health flags (bit 0 = degraded, bit 1 = recovery in progress)
static volatile uint8_t s_sensorStatusFlags = 0;
#define STATUS_DEGRADED       0x01
#define STATUS_RECOVERY_DONE  0x02

static SensorHealth s_health = {
    .mpu_present = false,
    .mpu_whoami = 0,
    .i2c_error_count = 0,
    .samples_total = 0,
    .samples_invalid = 0,
    .last_i2c_error_time = 0,
    .i2c_recovery_count = 0,
    .last_read_valid = false,
};

// I2C error tracking
uint8_t s_consecutiveErrors = 0;  // Non-static: accessed by recoveryTask in main.cpp
uint8_t s_recoveryFailCount = 0;
static uint8_t s_consecutiveInvalidReads = 0;
static bool s_recoveryInProgress = false;

// Last valid reading (for graceful degradation)
static int16_t s_lastAccel[3] = {0, 0, 0};
static int16_t s_lastGyro[3] = {0, 0, 0};

// Calibration data
static CalibrationData s_calData = {
    .accel_bias_x = 0, .accel_bias_y = 0, .accel_bias_z = 0,
    .gyro_bias_x = 0, .gyro_bias_y = 0, .gyro_bias_z = 0,
    .temp_coeff = 0,
    .mount_mode = 0,
    .is_calibrated = false,
    .factory_calibrated = false,
};

// ================= MPU6050 REGISTER OPERATIONS =================
void writeMPURegister(uint8_t reg, uint8_t val) {
    Wire.beginTransmission(MPU_ADDR);
    Wire.write(reg);
    Wire.write(val);
    Wire.endTransmission();
}

uint8_t readMPURegister(uint8_t reg) {
    Wire.beginTransmission(MPU_ADDR);
    Wire.write(reg);
    Wire.endTransmission(false);
    Wire.requestFrom((uint8_t)MPU_ADDR, (uint8_t)1, (uint8_t)1);
    if (Wire.available()) return Wire.read();
    return 0xFF;
}

// ================= ISR =================
static volatile bool s_dataReadyFlag = false;

void IRAM_ATTR mpuISR() {
    BaseType_t higherPriorityTaskWoken = pdFALSE;
    if (dataReadySem != NULL) {
        xSemaphoreGiveFromISR(dataReadySem, &higherPriorityTaskWoken);
    }
    s_dataReadyFlag = true;
    if (higherPriorityTaskWoken == pdTRUE) {
        portYIELD_FROM_ISR();
    }
}

// ================= MPU6050 INITIALIZATION =================
bool initMPU6050() {
    Wire.begin(I2C_SDA, I2C_SCL);
    Wire.setClock(400000); // 400kHz Fast I2C

    delay(50);

    // Check WHOAMI — accept both MPU6050 (0x68) and MPU6500 (0x70)
    uint8_t whoami = readMPURegister(MPU_REG_WHO_AM_I);
    s_health.mpu_whoami = whoami;
    s_health.mpu_present = (whoami == 0x68 || whoami == 0x70);
    if (!s_health.mpu_present) {
        Serial.printf("[SENSOR] MPU6050/6500 not found (WHOAMI=0x%02X)\n", whoami);
        return false;
    }
    if (whoami == 0x68) {
        Serial.printf("[SENSOR] MPU6050 found (WHOAMI=0x%02X)\n", whoami);
    } else {
        Serial.printf("[SENSOR] MPU6500 found (WHOAMI=0x%02X)\n", whoami);
    }

    // Wake up MPU6050
    writeMPURegister(MPU_REG_PWR_MGMT_1, 0x00);  // Clear sleep bit
    delay(50);

    // Disable I2C master mode (use I2C bypass for aux sensor access)
    writeMPURegister(MPU_REG_PWR_MGMT_1, 0x01);  // Clock = PLL with X gyro ref
    delay(50);

    // Accelerometer: 4G range (0x08)
    writeMPURegister(MPU_REG_ACCEL_CONFIG, 0x08);

    // Gyroscope: 500 dps range (0x08)
    writeMPURegister(MPU_REG_GYRO_CONFIG, 0x08);

    // DLPF: 188Hz bandwidth -> ~1kHz output rate (0x03)
    // DLPF 188Hz gives 1kHz sample rate with 8MHz internal clock
    writeMPURegister(MPU_REG_CONFIG, 0x03);

    // Sample rate divider: 0 -> 1kHz
    writeMPURegister(MPU_REG_SMPLRT_DIV, 0x00);

    // Enable data-ready interrupt
    writeMPURegister(MPU_REG_INT_ENABLE, 0x01);  // DATA_RDY_EN

    // Configure INT pin as push-pull, high until data ready
    writeMPURegister(0x37, 0x00);  // INT pin config (active low, push-pull)

    // Create binary semaphore for ISR
    if (dataReadySem == NULL) {
        dataReadySem = xSemaphoreCreateBinary();
        if (dataReadySem == NULL) {
            Serial.println("[SENSOR] ERROR: Failed to create data ready semaphore");
            return false;
        }
    }

    // Create recovery queue
    if (recoveryQueue == NULL) {
        recoveryQueue = xQueueCreate(1, sizeof(bool));
    }

    // Create recovery completion semaphore
    if (recoveryDoneSem == NULL) {
        recoveryDoneSem = xSemaphoreCreateBinary();
        // Take it initially so the first wait returns only on recovery completion
        xSemaphoreTake(recoveryDoneSem, 0);
    }

    // Attach interrupt to MPU INT pin
    pinMode(MPU_INT_PIN, INPUT_PULLUP);
    attachInterrupt(digitalPinToInterrupt(MPU_INT_PIN), mpuISR, RISING);

    // Load calibration data
    loadCalibrationData(&s_calData);
    Serial.printf("[SENSOR] Calibrated: %s, accel_bias=(%d,%d,%d)\n",
                 s_calData.is_calibrated ? "yes" : "no",
                 s_calData.accel_bias_x, s_calData.accel_bias_y, s_calData.accel_bias_z);

    Serial.println("[SENSOR] MPU6050 initialized: 4G / 500dps / DLPF_188Hz / INT enabled");
    return true;
}

// ================= BURST READ =================
// Forward declaration (defined later in this file)
static void applyMountRotation(int16_t* ax, int16_t* ay, int16_t* az);
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

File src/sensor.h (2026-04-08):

#ifndef SENSOR_H
#define SENSOR_H

#include <stdint.h>
#include <stdbool.h>
#include <freertos/FreeRTOS.h>
#include <freertos/semphr.h>

// ================= PINS =================
#define PIEZO_PIN        35   // ADC1_CH7 — safe with BT
#define MPU_INT_PIN       4    // GPIO for MPU6050 data-ready interrupt

// ================= I2C =================
#define I2C_SDA          21
#define I2C_SCL          22
#define MPU_ADDR         0x68

// ================= MPU6050 REGISTERS =================
#define MPU_REG_PWR_MGMT_1   0x6B
#define MPU_REG_PWR_MGMT_2   0x6C
#define MPU_REG_ACCEL_CONFIG 0x1C
#define MPU_REG_GYRO_CONFIG  0x1B
#define MPU_REG_CONFIG       0x1A    // DLPF
#define MPU_REG_INT_ENABLE   0x38
#define MPU_REG_INT_STATUS   0x3A
#define MPU_REG_WHO_AM_I     0x75
#define MPU_REG_SMPLRT_DIV    0x19
#define MPU_REG_ACCEL_XOUT_H 0x3B

// ================= RANGES =================
#define ACCEL_4G_LSB    8192.0   // LSB per g
#define GYRO_500DPS_LSB 65.5     // LSB per deg/s

// ================= SENSOR SAMPLE =================
struct SensorSample {
    uint32_t timestamp_us;
    int16_t  accel_x;
    int16_t  accel_y;
    int16_t  accel_z;
    int16_t  gyro_x;
    int16_t  gyro_y;
    int16_t  gyro_z;
    int16_t  temperature;   // raw register value
    uint16_t piezo;
    uint16_t piezo_raw;     // unfiltered raw ADC
    bool     valid;
};
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

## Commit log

2026-04-03 Initial commit: STASYS ESP32 firmware v1.0.1
    ESP32 firmware for shooting athlete training device. Captures muzzle
    trace movement and shot events via MPU6050 IMU and piezoelectric sensor.
    Includes Bluetooth Classic SPP protocol, OTA updates, session storage,
    shot detection, LED/haptic feedback, battery monitoring, and I2C recovery.
    [partitions_ota.csv]
2026-04-03 Update Bluetooth task priorities and stack sizing
    - Raise BluetoothTask priority from 2→3 to prevent RX starvation
    under high TX load
    - Increase stack from 4096→5120 bytes for deeper SPP call chain
    - Minor Bluetooth module improvements
    [bluetooth.cpp, main.cpp]
2026-04-03 Add Python companion app and fix aim trace rendering
    - Add full companion_app: PyQt6 GUI with live IMU trace plot, shot
    detection, session history, analysis, and settings tabs.
    - companion_app/ was previously gitignored — remove from .gitignore.
    - Fix tab_live.py aim trace: replace single PlotDataItem with 10-segment
    fading trail (alpha gradient from tail to head), cap trail at 150
    samples (~1.5s at 100Hz), use actual timestamp_us delta for gyro
    integration with gyro bias correction, fixed ±4° view range with
    no auto-range, solid filled dot at current position.
    - Fix src/protocol.cpp (already staged as modified).
    - Update CLAUDE.md: note that every edit should be committed and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
    [console.py]
2026-04-04 fix: commercial readiness — data integrity, security hardening, build infra
    Phase 0.2 — Fix known bugs:
    - Fix NVS reinit after factory reset (nvs_flash_erase now followed by nvs_flash_init)
    - Populate sensor health flags in EVT_SESSION_STARTED/STOPPED
    - Add getSensorHealthFlags() combining MPU fault, calibration needed, I2C error status
    Phase 1 — Security hardening:
    - Remove hardcoded fallback key "STASYS-DEVICE-KEY" — dev units now use MAC-only derivation (per-device, not shared)
    - Remove hardcoded PIN "1234" — session key now derived from first 4 bytes of device secret (per-device)
    - Add PRODUCTION_BUILD guard for FIRMWARE_IC_ID
    - Add checkSecurityStatus() at boot to report efus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
    [partitions_ota.csv]
2026-04-05 fix: resolve live tab "New Session" button unresponsive after connect
    Root cause: three parser bugs prevented the Python companion app from decoding ESP32 responses:
    1. DATA_RAW_SAMPLE field swap (parser.py):
    The Python parser assigned temperature and gyro_z to swapped struct positions.
    The C firmware PktRawSample sends: counter, ts, ax, ay, az, gx, gy, gz,
    gyro_z, temperature. The parser was reading the opposite order, causing all
    live trace values to be wrong. Also hardcoded piezo=0 (piezo is not in
    DATA_RAW_SAMPLE, only in EVT_SHOT_DETECTED).
    2. EVT_SESSION_STOPPED size mismatch (parser.py):
    Parser required 14 bytes minimum but firmware sends 12 bytes
    (session_id +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
    [bluetooth.cpp, loopback_test.py, main.cpp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]
2026-04-05 fix: NEW SESSION button freeze on Live tab
    Root cause: _on_session_toggle() had no pending state — the button
    remained "New Session" until EVT_SESSION_STARTED arrived, allowing
    double-clicks to queue multiple CMD_START_SESSION commands and leaving
    the UI permanently stuck if the response never arrived (BT dropout).
    Fix:
    - Add _session_pending flag to guard against double-click during wait
    - Show "Starting..." disabled state on button while waiting for response
    - Start 3-second QTimer; if no EVT_SESSION_STARTED arrives, revert
    button to idle "New Session" and show error in status bar
    - Cancel timer in _on_session_started / _on_session_stopped / _on_disconnect
    - Add set_session_starting()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
    [main_window.py]
2026-04-05 fix: connect timer to correct handler name
    [main_window.py]
2026-04-05 fix: EVT_SESSION_STARTED not received — stale session state + parser CRC debug + DATA_RAW_SAMPLE struct
    Root causes found and fixed:
    1. Firmware (bluetooth.cpp): handleStartSession() silently returned
    STREAMING when already streaming, sending a duplicate EVT_SESSION_STARTED
    with the OLD session ID and stale shot buffer. If the ESP32 had an
    active session from a prior connection (e.g. BT dropout without clean
    disconnect), a new CMD_START_SESSION would not start a fresh session.
    Fix: check getSessionState() == STREAMING before calling startSession();
    if stale, call stopSession() first to clean up, then start a new
    session with a fresh ID and cleared shot buffer.
    2. Pac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
    [bluetooth.cpp, loopback_test.py, test_protocol.py]
2026-04-05 fix: protocol RX CRC — accumulate over TYPE+LEN as continuous bytes
    CRC-16/CCITT must process bytes sequentially. The incremental XOR
    approach (CRC(TYPE) ^ CRC(LEN_LO) ^ CRC(LEN_HI)) produces a different
    value than CRC([TYPE, LEN_LO, LEN_HI]) because the shift register
    feedback in each byte pass depends on prior state.
    This prevented CMD_START_SESSION and all other commands from being
    decoded — the firmware discarded every incoming packet due to CRC
    mismatch, so handleStartSession() was never called.
    Fix applies to both the main g_decoder and the inner s_innerDecoder
    (used for encrypted packet decryption). The send side (encodePacket)
    was already correct — it uses crc16_ccitt(&outBuf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
    [protocol.cpp]
2026-04-05 docs: add Phase 3.15 — fix RX CRC accumulation
2026-04-05 fix: UI freeze under data load + remove crosshair from live plot
    Bug 1 — UI freeze under sustained data load:
    - tab_live.py: TRAIL_LENGTH 150→500, QTimer 16ms→30ms (~33fps), removed
    per-frame throttling since timer now caps update rate naturally.
    Plot data already used bounded deque(maxlen=N) — max cap raised.
    - data_logger.py: batch IMU writes. Accumulate samples in a list,
    flush to raw_store + session_store every 100 samples OR 1s (whichever
    first). Eliminates per-sample SQLite commit and per-sample numpy save.
    - raw_store.py: added record_imu_batch() — load existing .npy once,
    vstack entire batch, save once.
    - session_store.py: added record_imu_batch() — executemany(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
    [main_window.py, monitor.py, serial_transport.py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]
2026-04-06 fix: keep BT discoverable on battery — disable light sleep + max TX power
    - checkIdleSleep(): only allow light sleep when charging (externally powered).
    On battery, the device stays awake with BT always active.
    - bluetooth.cpp: boost TX power from +3dBm to +9dBm (P9) for better
    range/reliability on battery power.
    Fixes: Windows cannot pair/connect to ESP32 when running on battery
    (no USB) because light sleep was disabling the Bluetooth Classic radio.
    [bluetooth.cpp, main.cpp]
2026-04-06 docs: update CLAUDE.md to reflect full codebase state
    Major changes:
    - Add CLAUDE.md maintenance rule at top
    - Add all GUI components (tab_live, tab_shot_detail, tab_analysis, tab_history, tab_settings, theme, score_gauge, direction_wheel, status_bar)
    - Add all tools (console.py, monitor.py, replay.py, scan_ports.py, loopback_test.py, hw_test.py)
    - Fix EVT_SENSOR_HEALTH payload size (13→11 bytes) and RSP_OTA_STATUS (add partition_address field)
    - Fix BT TX power max setting (+9dBm P9), power management note (no sleep on battery)
    - Add XON(0x11)/XOFF(0x13) values and raw-byte flow control note
    - Add session storage details (SPIFFS path format, enumerate/download/delete flow)
    - Add coredump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
2026-04-06 diagnostic: improve session-start visibility
    - PARSER_DEBUG=True by default so EVT_SESSION_STARTED arrival and CRC
    validation are visible immediately on startup
    - Session start timeout raised from 3s to 5s to accommodate Windows BT
    SPP (bthmodem.sys) hardware-level batching which can delay small
    packets by 50-100ms, plus stale-session SPIFFS write overhead
    - Basic logging.basicConfig(DEBUG) wired into main.py entry point so
    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
2026-04-06 fix: add TX hex dump + log exception in packet reader
    - Log the raw hex bytes of CMD_START_SESSION so we can confirm the
    command is actually being written to the serial port
    - Replace silent `except Exception: break` with logger.exception()
    so packet-reader crashes are visible instead of invisible
    [main_window.py]
2026-04-06 fix: disable REQUIRE_AUTH to fix session-start timeout
    Root cause: platformio.ini had -DREQUIRE_AUTH=1, causing the firmware to
    send EVT_AUTH_CHALLENGE (type 0x14) instead of EVT_SESSION_STARTED on
    CMD_START_SESSION. The Python app never implemented the HMAC-SHA256
    auth response, so it waited for EVT_SESSION_STARTED and timed out.
    Fixes:
    - platformio.ini: changed -DREQUIRE_AUTH=1 to -DREQUIRE_AUTH=0
    - bluetooth.cpp: changed #ifdef REQUIRE_AUTH to #ifndef REQUIRE_AUTH
    so the preprocessor guard correctly checks undefinedness, not just
    definedness. This also fixes the stale-session guard logic to be
    active in dev mode builds.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
    [bluetooth.cpp]
2026-04-06 feat: add parametric 3D-printable enclosure + extend firmware mount modes
    Firmware:
    - sensor.cpp: extend applyMountRotation() with X/Y axis rotations for
    barrel-under (modes 4-5) and side-mount (mode 6) orientations
    - config.h: document mount_mode values 0-6
    - bluetooth.cpp: update handleSetMountMode() to accept 0-7
    Companion app:
    - packets.py: add CMD_SET_MOUNT_MODE = 0x25
    - commands.py: add cmd_set_mount_mode() encoder
    - tab_settings.py: replace USB direction group with MOUNT POSITION
    selector (modes 0-6) with Apply button over BT
    Enclosure (new files):
    - STASYS_enclosure.scad: full parametric model (assembly view)
    - enclosure_base.scad: base half with Picatinny 2-slot mount, cross-b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
    [STASYS_enclosure.scad, enclosure_base.scad, enclosure_lid.scad]
2026-04-07 feat: add Picatinny adapter bracket + reorganize files into ENCLOSURE/
    - NEW: ENCLOSURE/picatinny_adapter.scad — L-bracket that bolts to the 4
    existing corner bosses on the watch-style case, adds Picatinny rail
    mount. M2 bolts to case, M3 cross-bolt for rail. Hex socket top-access.
    - NEW: ENCLOSURE/MainCase watch esp 32.stl — user's existing case body
    - NEW: ENCLOSURE/Lid watch esp 32.stl — user's existing lid
    - MOVE: STASYS_enclosure.scad, enclosure_base.scad, enclosure_lid.scad,
    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
    [Lid watch esp 32.stl, MainCase watch esp 32.stl, STASYS_enclosure.scad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]
2026-04-07 fix: update picatinny_adapter.scad with exact STL measurements
    - Precise boss positions from STL analysis:
    BL: (-27.9, -18.9), BR: (35.4, -18.9), TL: (-27.4, 18.1), TR: (34.3, 18.6)
    - Boss diameter: 3.8mm (M3 clearance)
    - Adapter body: 70x52x6mm flat plate on case bottom
    - Picatinny body: 24x52x10mm (2-slot), centered on case
    - Recoil lugs: 4.5x3mm, centered in slots
    - All 4 bosses used for maximum recoil resistance
    - M3 mounting screws through flat bottom into bosses
    [picatinny_adapter.scad]
2026-04-07 fix: replace accel double-integration with tilt angle for dot position
    Dot drifted away from origin after calibration due to double-integration
    of residual accelerometer bias (position grows as t² even with perfect
    bias subtraction). Replaced with tilt-angle computation via atan2 on
    calibrated accel_x/y/z, giving roll/pitch in degrees. This approach:
    - Cannot drift (bounded by ±90° physics)
    - Returns to 0,0 when device returns to level
    - Requires no high-pass filter or dead-zone hacks
    Also: update plot axis labels from m/s² to degrees, update coordinate
    readout to show degrees, and document in CLAUDE.md.
    [tab_live.py]
2026-04-08 fix: correct CLAUDE.md discrepancies with actual code
    - DATA_RAW_SAMPLE: 24 → 26 bytes
    - RSP_CONFIG/CMD_SET_CONFIG: 46 → 50 bytes (reserved 15 → 19)
    - RSP_OTA_STATUS: 9 → 10 bytes (reserved 1 → 2)
    - Stale session guard: clarify it guards auth-enabled path, not dev path
    - Remove fabricated 5s session start timeout (does not exist in code)
    - Adaptive thresholds: clarify live detection (mean+2*stddev) vs
    printed suggestion (mean-0.5*stddev) are different formulas
2026-04-08 feat: add serial debug output for sensor degradation diagnostics
    Adds [SENSOR] debug prints at every degradation decision point:
    - I2C error (consecutive count, recovery_in_progress)
    - Recovery trigger (consecutiveErrors value)
    - Recovery result (success/fail, fail_count)
    - Invalid read path (consecutiveInvalidReads count)
    - Health packet send (degraded flag, recovery flag, error counts)
    Also exposes g_recoverySuccess and s_recoveryFailCount as non-static
    for RecoveryTask debug logging from main.cpp.
    [bluetooth.cpp, main.cpp, sensor.cpp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]
2026-04-08 fix: reduce default streaming rate from 100Hz to 50Hz
    Windows BT SPP virtual COM port has limited effective throughput
    (~2-3 KB/s). At 100Hz (32-byte packets = ~3.2 KB/s), the TX queue
    backs up behind the raw data stream, delaying command-response
    packets (EVT_SESSION_STARTED, EVT_SENSOR_HEALTH) and causing CRC
    corruption from RFCOMM buffer overflow.
    At 50Hz, throughput is ~1.6 KB/s — well within SPP limits. Critical
    control packets get sent immediately instead of queuing behind samples.
    Also adds streaming rate to the [CONFIG] debug line.
    [config.cpp, config.h]
2026-04-09 feat: priority TX queuing — control packets bypass sample stream
    Control/event packets now send via sendPacketImmediate() which writes
    directly to SerialBT, bypassing the TX queue entirely. Only DATA_RAW_SAMPLE
    remains queued. This prevents the 100 Hz sample stream from blocking
    command responses (SESSION_STARTED, SENSOR_HEALTH, ACK, ERROR, etc.).
    Also restored DEFAULT_STREAMING_RATE to 100 Hz.
    Affected packets: RSP_INFO, RSP_CONFIG, RSP_ACK, RSP_ERROR, RSP_OTA_STATUS,
    EVT_SESSION_STARTED, EVT_SESSION_STOPPED, EVT_SHOT_DETECTED,
    EVT_SENSOR_HEALTH, EVT_AUTH_CHALLENGE, EVT_CALIBRATION_QUALITY,
    EVT_SESSION_ENUM, EVT_SESSION_DATA, calibration data, coredump chunks.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
    [bluetooth.cpp, config.h, main.cpp]
2026-04-09 docs: update CLAUDE.md — add priority TX queuing to Phase 3.9
2026-04-09 feat: BT connection robustness, complementary filter dot trace, and port auto-discovery
    - **serial_transport.py**: Major BT connection improvements:
    - Dual-port discovery: find_stasys_ports() returns (outgoing, incoming) tuple
    using ESP32SPP/OUTGOING/INCOMING keywords in port description
    - Auto-discovery in connect() when no port specified (GUI auto-scan)
    - Bluetooth handshake retries (winerror 121 RFCOMM timeout, winerror 31 radio
    glitch): 3 retries with 2s delay each
    - 500ms post-open settling delay for ESP32 BT stack readiness
    - Port existence validation before open (catches stale saved ports)
    - _parser set AFTER connect() returns; _packet_reader buffer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
    [main_window.py, scan_ports.py, serial_transport.py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]
2026-04-09 fix: critical protocol bugs — shot events dropped, config rejected, temp/piezo swap
    Root cause investigation across firmware + companion app protocol layers:
    1. EVT_SHOT_DETECTED: Parser required 29 bytes; firmware sends 26.
    Every shot event was silently dropped (ValueError → RawPacket).
    Also fixed recoil_axis/sign offsets (26-27 → 24-25).
    2. DATA_RAW_SAMPLE: Parser had temperature/piezo fields swapped and
    hardcoded piezo=0. Fixed struct layout to match firmware PktRawSample
    field order (counter,ts,ax,ay,az,gx,gy,gz,temp,piezo).
    3. CMD_SET_CONFIG: Python sent 46 bytes; firmware expects 50.
    All config commands were rejected. Fixed to 50 bytes.
    4. FLOW_XON: Was 0x14 (D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
    [loopback_test.py, test_monitor.py, test_protocol.py]
2026-04-11 fix: disable live tab plot rendering to reduce main-thread overhead
    Live tab visualization moved to background DataLogger — Qt main thread
    no longer processes per-packet signal handlers. Timer kept at 33 Hz for
    UI responsiveness. Trace re-centering fixed to avoid deque clear on pan.
    [tab_live.py]
